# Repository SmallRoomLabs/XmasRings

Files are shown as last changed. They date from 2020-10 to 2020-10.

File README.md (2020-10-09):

# XmasRings

These are cheap 10x10 cm PCBs that are routed/cut into seven rings holding a total of 45 LEDs with individual control using Charlieplexing with a PIC16F1705 microcontroller. There are a couple of different light pattern that it it cycling though.

YouTube video of several XmasRings running (https://www.youtube.com/watch?v=cKff3fn9ruI)

Click image to play video from YouTube

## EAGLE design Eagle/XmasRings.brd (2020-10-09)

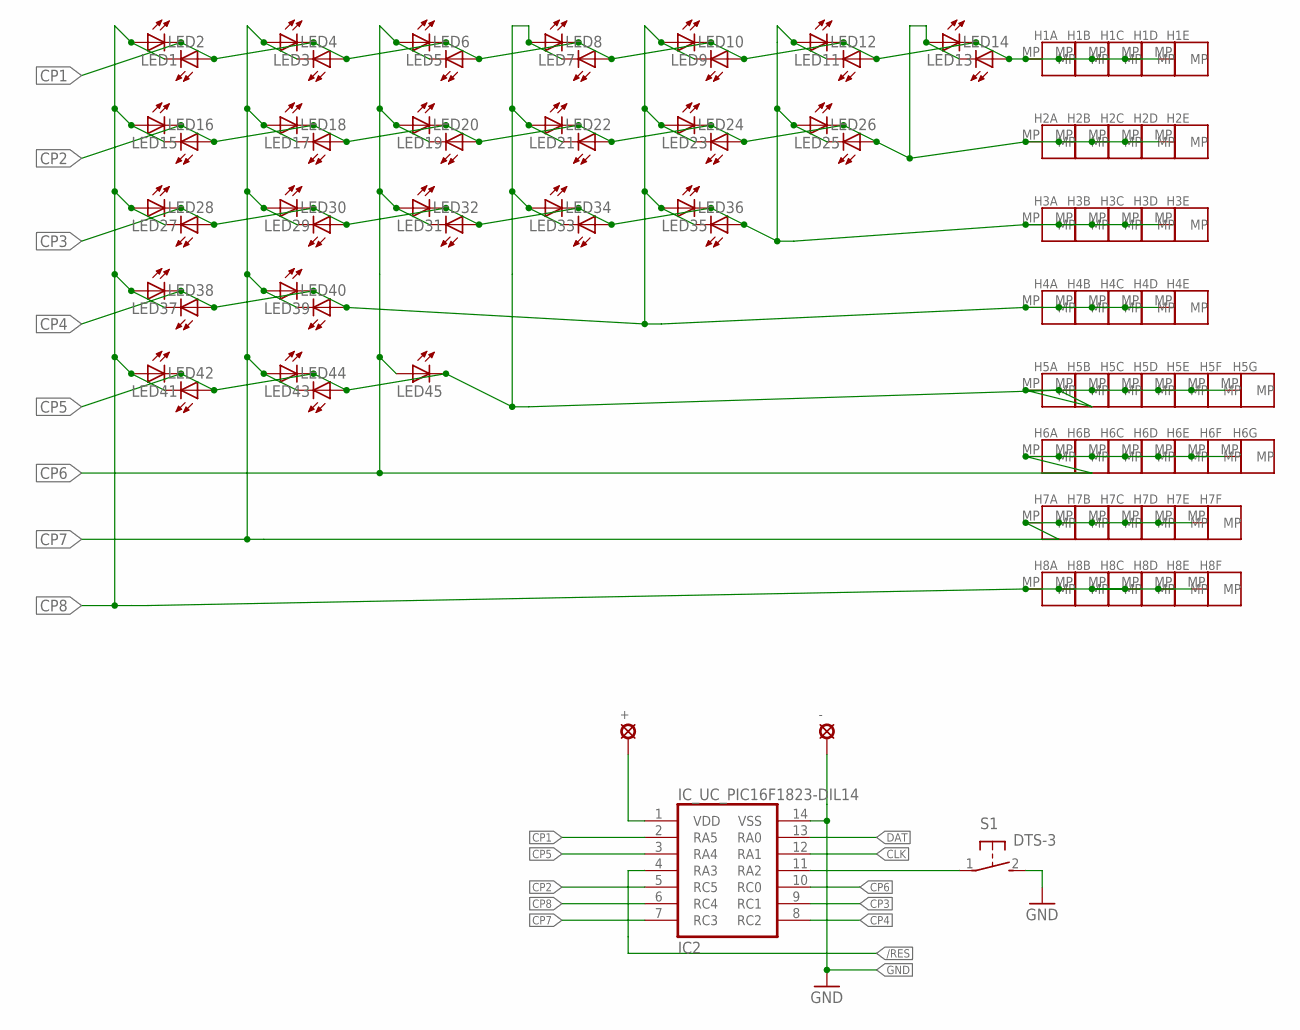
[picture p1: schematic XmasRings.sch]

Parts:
+: LSP10
-: LSP10
H1A, H1B, H1C, H1D, H1E, H2A, H2B, H2C, H2D, H2E, H3A, H3B, H3C, H3D, H3E, H4A, H4B, H4C, H4D, H4E, H5A, H5B, H5C, H5D, H5E, H5F, H5G, H6A, H6B, H6C, H6D, H6E, H6F, H6G, H7A, H7B, H7C, H7D, H7E, H7F, H8A, H8B, H8C, H8D, H8E, H8F: PADH08SS; PAD08SS
IC2: IC_UC_PIC16F1823-DIL14; DIP14
LED1, LED2, LED3, LED4, LED5, LED6, LED7, LED8, LED9, LED10, LED11, LED12, LED13, LED14, LED15, LED16, LED17, LED18, LED19, LED20, LED21, LED22, LED23, LED24, LED25, LED26, LED27, LED28, LED29, LED30, LED31, LED32, LED33, LED34, LED35, LED36, LED37, LED38, LED39, LED40, LED41, LED42, LED43, LED44, LED45: LED5SQ; 5MM-SQ
S1: DTS-3

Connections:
/RES: IC2.4 (RA3)
CLK: IC2.12 (RA1)
CP1: H1A.MP, H1B.MP, H1C.MP, H1D.MP, H1E.MP, IC2.2 (RA5), LED1.C, LED2.A, LED3.C, LED4.A, LED5.C, LED6.A, LED7.C, LED8.A, LED9.C, LED10.A, LED11.C, LED12.A, LED13.C, LED14.A
CP2: H2A.MP, H2B.MP, H2C.MP, H2D.MP, H2E.MP, IC2.5 (RC5), LED13.A, LED14.C, LED15.C, LED16.A, LED17.C, LED18.A, LED19.C, LED20.A, LED21.C, LED22.A, LED23.C, LED24.A, LED25.C, LED26.A
CP3: H3A.MP, H3B.MP, H3C.MP, H3D.MP, H3E.MP, IC2.9 (RC1), LED11.A, LED12.C, LED25.A, LED26.C, LED27.C, LED28.A, LED29.C, LED30.A, LED31.C, LED32.A, LED33.C, LED34.A, LED35.C, LED36.A
CP4: H4A.MP, H4B.MP, H4C.MP, H4D.MP, H4E.MP, IC2.8 (RC2), LED9.A, LED10.C, LED23.A, LED24.C, LED35.A, LED36.C, LED37.C, LED38.A, LED39.C, LED40.A
CP5: H5A.MP, H5B.MP, H5C.MP, H5D.MP, H5E.MP, H5F.MP, H5G.MP, IC2.3 (RA4), LED7.A, LED8.C, LED21.A, LED22.C, LED33.A, LED34.C, LED41.C, LED42.A, LED43.C, LED44.A, LED45.C
CP6: H6A.MP, H6B.MP, H6C.MP, H6D.MP, H6E.MP, H6F.MP, H6G.MP, IC2.10 (RC0), LED5.A, LED6.C, LED19.A, LED20.C, LED31.A, LED32.C, LED45.A
CP7: H7A.MP, H7B.MP, H7C.MP, H7D.MP, H7E.MP, H7F.MP, IC2.7 (RC3), LED3.A, LED4.C, LED17.A, LED18.C, LED29.A, LED30.C, LED39.A, LED40.C, LED43.A, LED44.C
CP8: H8A.MP, H8B.MP, H8C.MP, H8D.MP, H8E.MP, H8F.MP, IC2.6 (RC4), LED1.A, LED2.C, LED15.A, LED16.C, LED27.A, LED28.C, LED37.A, LED38.C, LED41.A, LED42.C
DAT: IC2.13 (RA0)
GND: -.MP, IC2.14 (VSS), S1.2
unnamed: IC2.11 (RA2), S1.1
VCC: +.MP, IC2.1 (VDD)

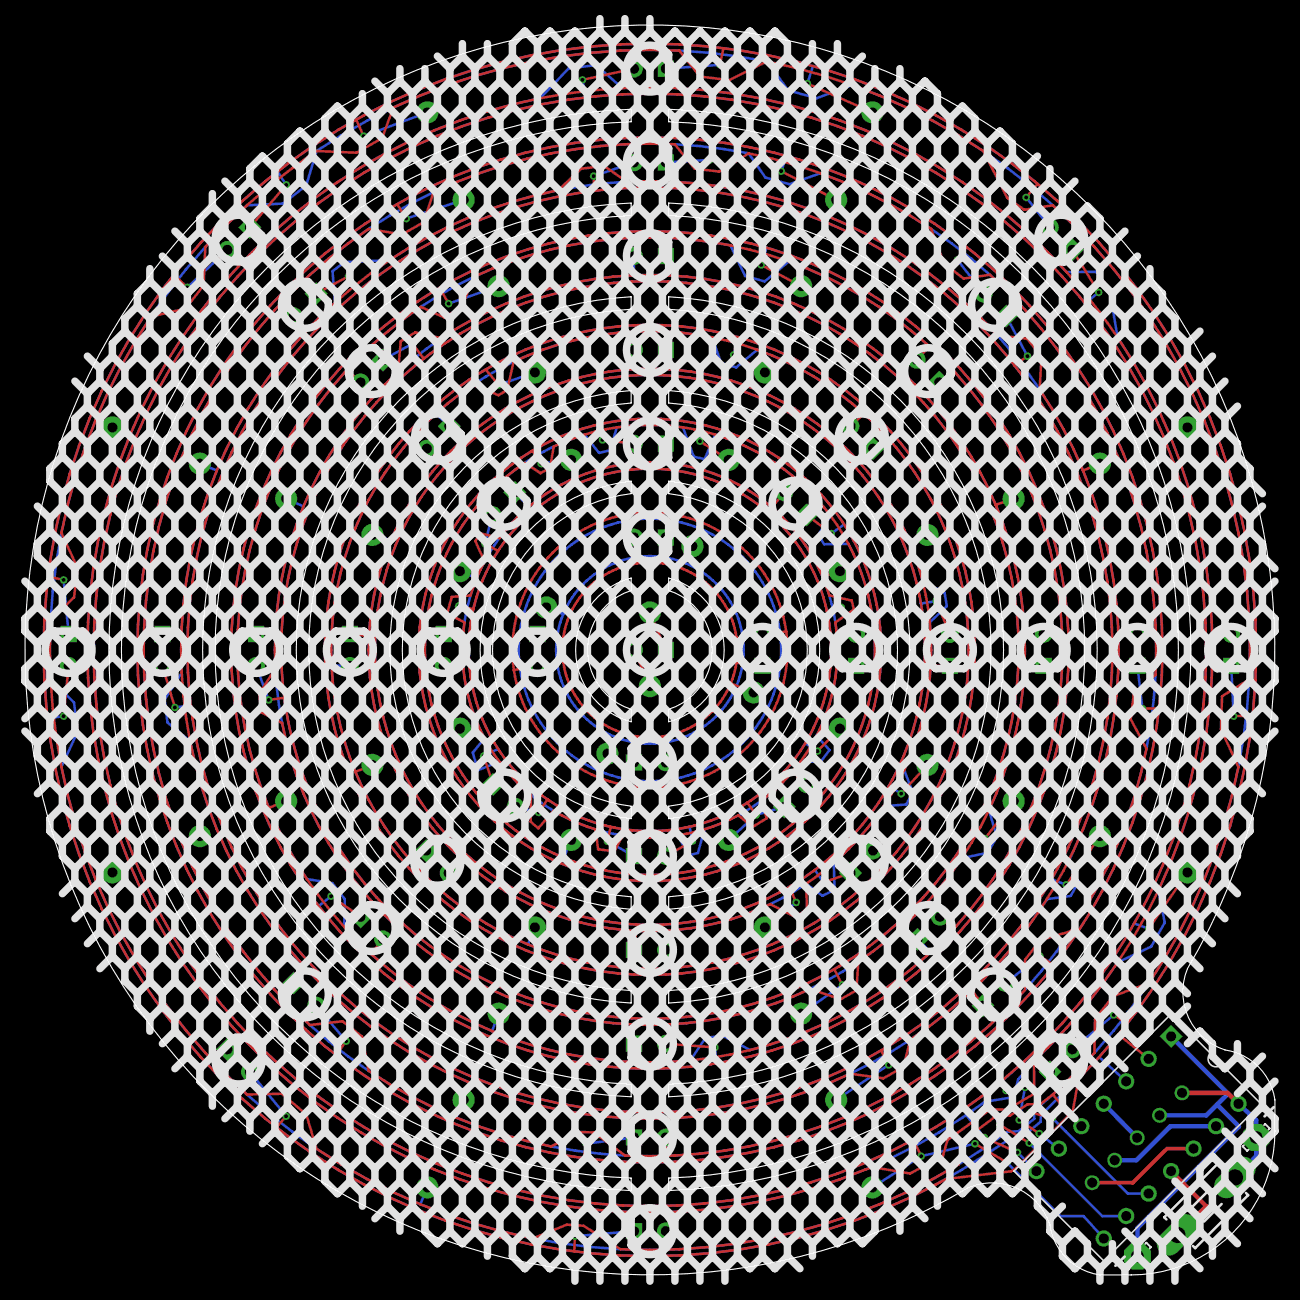
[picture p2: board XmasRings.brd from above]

Board: 2 copper layers, 100.0 x 100.0 mm, 95 parts (0 on the bottom side), 11 nets.

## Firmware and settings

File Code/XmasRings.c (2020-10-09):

//
// PIC16F1705 code for the XmasTree
// Project located at github.com/SmallRoomLabs/XmasRings
// Copright (c) 2016 Mats Engstrom SmallRoomLabs
// Released under the MIT license
//

#define _XTAL_FREQ 32000000

#include <stdint.h>
#include <stdlib.h>
#include <string.h>
#include <xc.h>

#define T0_DIV256 0b0111
#define T0_DIV128 0b0110
#define T0_DIV64  0b0101
#define T0_DIV32  0b0100
#define T0_DIV16  0b0011
#define T0_DIV8   0b0010
#define T0_DIV4   0b0001
#define T0_DIV2   0b0000
#define T0_DIV1   0b1000

// PIC16F1705 Configuration Bit Settings
#pragma config FOSC = INTOSC    // Oscillator Selection Bits (INTOSC oscillator: I/O function on CLKIN pin)
#pragma config WDTE = OFF       // Watchdog Timer Enable (WDT disabled)
#pragma config PWRTE = ON       // Power-up Timer Enable (PWRT enabled)
#pragma config MCLRE = ON       // MCLR Pin Function Select (MCLR/VPP pin function is MCLR)
#pragma config CP = OFF         // Flash Program Memory Code Protection (Program memory code protection is disabled)
#pragma config BOREN = OFF      // Brown-out Reset Enable (Brown-out Reset disabled)
#pragma config CLKOUTEN = OFF   // Clock Out Enable (CLKOUT function is disabled. I/O or oscillator function on the CLKOUT pin)
#pragma config IESO = OFF       // Internal/External Switchover Mode (Internal/External Switchover Mode is disabled)
#pragma config FCMEN = OFF      // Fail-Safe Clock Monitor Enable (Fail-Safe Clock Monitor is disabled)
#pragma config WRT = OFF        // Flash Memory Self-Write Protection (Write protection off)
#pragma config PPS1WAY = ON     // Peripheral Pin Select one-way control (The PPSLOCK bit cannot be cleared once it is set by software)
#pragma config ZCDDIS = ON      // Zero-cross detect disable (Zero-cross detect circuit is disabled at POR)
#pragma config PLLEN = ON       // Phase Lock Loop enable (4x PLL is always enabled)
#pragma config STVREN = ON      // Stack Overflow/Underflow Reset Enable (Stack Overflow or Underflow will cause a Reset)
#pragma config BORV = LO        // Brown-out Reset Voltage Selection (Brown-out Reset Voltage (Vbor), low trip point selected.)
#pragma config LPBOR = OFF      // Low-Power Brown Out Reset (Low-Power BOR is disabled)
#pragma config LVP = ON         // Low-Voltage Programming Enable (Low-voltage programming enabled)

// #pragma config IDLOC0 = 0x01	// Set the User ID data to some
// #pragma config IDLOC1 = 0x23    // values for testing
// #pragma config IDLOC2 = 0x45
// #pragma config IDLOC3 = 0x56

// Defines of bitmasks to make the charlieplex table easier to write
#define b0 (1<<0)   
#define b1 (1<<1)
#define b2 (1<<2)
#define b3 (1<<3)
#define b4 (1<<4)
#define b5 (1<<5)


#define NUMBEROFLEDS  45    // The tree have 45 LEDs in total

//
// This table holds the values for the TRIS and LAT reigsters to
// setup the GPIOs correctly to light up the specified LED
//
const uint8_t charlie[NUMBEROFLEDS*4]={
// TRISA         TRISC         LATA LATC
// ============  ============  ==== ====
   0xFF^(b5|b4), 0xFF^0,       b5,  0,   //  0 1a-5a  RING1
   0xFF^(b5|b4), 0xFF^0,       b4,  0,   //  1 5a-1a
   0xFF^b5,      0xFF^b0,      b5,  0,   //  2 1a-6c
   0xFF^b5,      0xFF^b0,      0,   b0,  //  3 6c-1a
   0xFF^b5,      0xFF^b3,      b5,  0,   //  4 1a-7c
   0xFF^b5,      0xFF^b3,      0,   b3,  //  5 7c-1a
   0xFF^b5,      0xFF^b4,      b5,  0,   //  6 1a-8c
   0xFF^b5,      0xFF^b4,      0,   b4,  //  7 8c-1a

   0xFF^0,       0xFF^(b4|b5), 0,   b5,  //  8 C4 C5  RING2
   0xFF^0,       0xFF^(b4|b5), 0,   b4,  //  9 C5 C4
   0xFF^b5,      0xFF^b5,      b5,  0,   // 10 A5 C5
   0xFF^b5,      0xFF^b5,      0,   b5,  // 11 C5 A5
   0xFF^b5,      0xFF^b1,      b5,  0,   // 12 A5 C1
   0xFF^b5,      0xFF^b1,      0,   b1,  // 13 C1 A5
   0xFF^b5,      0xFF^b2,      b5,  0,   // 14 A5 C4
   0xFF^b5,      0xFF^b2,      0,   b2,  // 15 C4 A5

   0xFF^0,       0xFF^(b2|b5), 0,   b5,  // 16 RC5 RC2  RING3
   0xFF^0,       0xFF^(b2|b5), 0,   b2,  // 17 RC2 RC5
   0xFF^b4,      0xFF^b5,      0,   b5,  // 18 RC5 RA4
   0xFF^b4,      0xFF^b5,      b4,  0,   // 19 RA4 RC5
   0xFF^0,       0xFF^(b0|b5), 0,   b5,  // 20 RC5 RC0
   0xFF^0,       0xFF^(b0|b5), 0,   b0,  // 21 RC0 RC5
   0xFF^0,       0xFF^(b3|b5), 0,   b5,  // 22 RC5 RC3
   0xFF^0,       0xFF^(b3|b5), 0,   b3,  // 23 RC3 RC5

   0xFF^0,       0xFF^(b0|b1), 0,   b1,  // 24 C1 C0  RING4
   0xFF^0,       0xFF^(b0|b1), 0,   b0,  // 25 C0 C1
   0xFF^0,       0xFF^(b1|b3), 0,   b1,  // 26 C1 C3
   0xFF^0,       0xFF^(b1|b3), 0,   b3,  // 27 C3 C1
   0xFF^0,       0xFF^(b1|b4), 0,   b1,  // 28 C1 C4
   0xFF^0,       0xFF^(b1|b4), 0,   b4,  // 29 C4 C1
   0xFF^0,       0xFF^(b1|b5), 0,   b5,  // 30 C5 C1
   0xFF^0,       0xFF^(b1|b5), 0,   b1,  // 31 C1 C5

   0xFF^0,       0xFF^(b2|b3), 0,   b2,  // 32 C2 C3  RING 5
   0xFF^0,       0xFF^(b2|b3), 0,   b3,  // 33 C3 C2
   0xFF^0,       0xFF^(b2|b4), 0,   b2,  // 34 C2 C4
   0xFF^0,       0xFF^(b2|b4), 0,   b4,  // 35 C4 C2
   0xFF^0,       0xFF^(b1|b2), 0,   b1,  // 36 C1 C2
   0xFF^0,       0xFF^(b1|b2), 0,   b2,  // 37 C2 C1
   0xFF^b4,      0xFF^b1,      0,   b1,  // 38 A4 C1
   0xFF^b4,      0xFF^b1,      b4,  0,   // 39 C1 A4

   0xFF^b4,      0xFF^b3,      b4,  0,   // 40 A4 C3  RING 6 (SMALL)
   0xFF^b4,      0xFF^b3,      0,   b3,  // 41 C3 A4
   0xFF^b4,      0xFF^b4,      b4,  0,   // 42 A4 C4
   0xFF^b4,      0xFF^b4,      0,   b4,  // 43 C4 A4

   0xFF^b4,      0xFF^b0,      0,   b0,  // 44 C0 A4  RING 7 (SINGLE)
};

volatile uint8_t tick=0;                // Incremened by IRQ at 0.1s rate
volatile uint8_t ledsOn[NUMBEROFLEDS];
volatile uint8_t maxLitLeds=1;
volatile uint8_t done=0;
uint8_t mode=0;				// Mode 0=Auto change

//
// 0          1          2          3           4          5          6
// 01234567 89012345 67890123 45678901 23456789 01234567 89012345 67890123
//
// 01234567 01234567 01234567 01234567 01234567 01234567 01234567 01234567
//
// LLLLLLLL LLLLLLLL LLLLLLLL LLLLLLLL LLLLLLLL LLLLLmmm mmmmdddd dddddddd
//


//
// Delays the specified time. Return true if button is pressed
//
uint8_t ButtonDelay(uint8_t ms) {
//  while ((ms-- > 0) && (PORTA&(1<<2)) ) {
  while ((ms-- > 0)) {
    __delay_ms(1);
    if (done) return 1;
  }

//  if (PORTA&(1<<2)) {
//    __delay_ms(100);
//    while (!(PORTA&(1<<2))) {};
//    mode++;
//    if (mode>9) mode=0;
//    return 1;
//  }

  return 0;
}


// Macro for turning off all LEDs
#define AllLedOff()  memset(ledsOn,0xFF,NUMBEROFLEDS)

//
// Turn of all LEDs in the specified ring
//
void RingOn(uint8_t ring, uint8_t clear) {
  if (clear) AllLedOff();
  if (ring<5) {
      for (uint8_t i=0; i<8; i++) {
        ledsOn[i]=i+ring*8;
      }
  } else if (ring==5) {
    ledsOn[0]=40;
    ledsOn[1]=41;
    ledsOn[2]=42;
    ledsOn[3]=43;
  } else {
    ledsOn[0]=44;
  }
}

//
// Show animated rings.
//   mode=0 - Go up from largest to smallest
//   mode=1 - Go down from smallest to largest
//   mode-2 - Go up and down
//
void RingUpDown(uint8_t mode) {
  maxLitLeds=8;
  do {
    if (mode==0 || mode==2) {
      for (uint8_t i=0; i<7; i++) {
        RingOn(i,1);  
        if (ButtonDelay(200)) {done=1; break;}
      }
    } 

    if (mode==1) {
      for (uint8_t i=6; i<=6; i--) {
        RingOn(i,1);  
        if (ButtonDelay(200)) {done=1; break;}
      }
    }
    if (mode==2) {
      for (uint8_t i=5; i>0; i--) {
        RingOn(i,1);
        if (ButtonDelay(200)) {done=1; break;}
      }
    }
  } while (!done);
}


//
// Make the top two rings fade in/out while
// flashing a random pixel at the remaining rinds
//
void PulseTopRandomPixel() {
  int8_t dir=1;

  AllLedOff();
  maxLitLeds=1;
  ledsOn[0]=44;
  ledsOn[1]=43;
  ledsOn[2]=42;
  ledsOn[3]=41;
  ledsOn[4]=40;
  do {
    for (uint16_t i=0; i<7; i++) {
      if ((rand()&127)>120) { 
        ledsOn[5]=rand()%40;
      } else {
        ledsOn[5]=0xFF;
      }
    if (ButtonDelay(5)) done=1;
    }
    maxLitLeds+=dir;
    if (maxLitLeds==30) dir=-1;
    if (maxLitLeds==5) dir=1;
  } while (!done);
}



//
// Raindrops falling down from top LED
//

void Rain() {
  uint8_t cnt=0;

  const uint8_t below40[]={32,33,33,34}; 
  const uint8_t below41[]={34,35,35,36};
  const uint8_t below42[]={36,37,37,38};
  const uint8_t below43[]={38,39,39,32};

  maxLitLeds=4;
  AllLedOff();
  do {
    if (cnt++ == 1) {
      cnt=0;
      if (ledsOn[0]==0xFF) {
        ledsOn[0]=44;
      } else if (ledsOn[1]==0xFF) {
        ledsOn[1]=44;
      } else if (ledsOn[2]==0xFF) {
        ledsOn[2]=44;
      } else if (ledsOn[3]==0xFF) {
        ledsOn[3]=44;
      }
    }
    if (ButtonDelay(150)) done=1;
    for (uint8_t i=0; i<maxLitLeds; i++) {
      if (ledsOn[i]==0xFF) continue;
      if (ledsOn[i]==44) {
        ledsOn[i]=40+(rand()&0x03);
      } else if (ledsOn[i]==40) { 
        ledsOn[i]=below40[rand()&0x03];
      } else if (ledsOn[i]==41) { 
        ledsOn[i]=below41[rand()&0x03];
      } else if (ledsOn[i]==42) { 
        ledsOn[i]=below42[rand()&0x03];
      } else if (ledsOn[i]==43) { 
        ledsOn[i]=below43[rand()&0x03];
      } else if (ledsOn[i]>=8) {
        ledsOn[i]-=8;
      } else {
        ledsOn[i]=0xff;
      }
    }
  } while (!done);
}


//
// Random blibs that gets more and more then less
//
void RandomSlowBlips() {
  do {
    for (maxLitLeds=1; maxLitLeds<10; maxLitLeds++) {
      for (uint8_t j=0; j<2; j++) { 
        AllLedOff();
        for (uint8_t i=0; i<maxLitLeds; i++) {
          ledsOn[i]=rand()%NUMBEROFLEDS;
        }    
        if (ButtonDelay(200)) return;
      }
    }
    for (maxLitLeds=9; maxLitLeds>1; maxLitLeds--) {
      for (uint8_t j=0; j<2; j++) { 
        AllLedOff();
        for (uint8_t i=0; i<maxLitLeds; i++) {
          ledsOn[i]=rand()%NUMBEROFLEDS;
        }    
        if (ButtonDelay(200)) return;
      }
    }
  } while (!done);
}


//
// Quck flickering of all leds
//
void Frussel() {
  maxLitLeds=8;
  do {
    for (uint8_t i=0; i<maxLitLeds; i++) {
      ledsOn[i]=rand()%NUMBEROFLEDS;
    }    
    if (ButtonDelay(1)) return;
  } while (!done);
}


//
//
//
void SpiralUpDown() {
  for (uint8_t i=0; i<NUMBEROFLEDS; i++) ledsOn[i]=i;
  do {
    for (maxLitLeds=1; maxLitLeds<NUMBEROFLEDS; maxLitLeds++) {
      if (ButtonDelay(50)) return;
    }      
    for (maxLitLeds=NUMBEROFLEDS; maxLitLeds>1; maxLitLeds--) {
      if (ButtonDelay(50)) return;
    }      
  } while (!done); 
}


//
//
//
void SpiralAway() {
  AllLedOff();
  maxLitLeds=NUMBEROFLEDS;
  do {
    for (uint8_t i=0; i<NUMBEROFLEDS; i++) {
      ledsOn[i]=i;
      if (ButtonDelay(50)) return;
    }
    if (ButtonDelay(50)) return;
    for (uint8_t i=0; i<NUMBEROFLEDS; i++) {
      ledsOn[i]=0xFF;
      if (ButtonDelay(50)) return;
    }
  } while (!done); 
}


//
//
//
void main() {
  OSCCON=0b11110000;		// Use internal oscillator set at 32MHz

  INTCON=0;             // Disable all interrupts
  PIE1=0;               // Disable peripheral interrupts
  PIE2=0;               // Disable more peripheral interrupts
  PIE3=0;               // Disable even more peripheral interrupts
  IOCAN=0x00;           // Disable pin-change interrupts
  IOCAP=0x00;
  IOCCN=0x00;
  IOCCP=0x00;

  ANSELA=0;			        // All GPIOs are digital
  ANSELC=0;
  WPUA=(1<<2);			    // Turn on pullup for the button
  WPUC=0;			          // No pullups at port C
  TRISA=0xFF;			      // All GPIOs are input until the charlieplexing in the IRQ
  TRISC=0xFF;           //   says otherwise

  //
  // Setup Timer0 to generate interrupts at about 4KHz for refreshing
  // the LEDs.  Even if all 45 LEDs are lit/processed the refresh rate
  // will be a flicker-free 87Hz.
  //
  //   fOsc/4      Prescale     8bit counter   45 Leds      
  // 32000000/4 -> 8000000/8 -> 1000000/256 -> 3926/45 -> 87 Hz Refresh 
  //
  OPTION_REG=0x00 | T0_DIV8;    // Wpu enabled, Prescale T0 from Fosc/4 with 8 
  INTCONbits.T0IE=1;            // Enable interrupt on TMR0 overflow
  INTCONbits.GIE=1;             // Global interrupt enable

  AllLedOff();
  for (;;) {
    if (mode==0 || mode==1) {PulseTopRandomPixel(); while (done);}
    if (mode==0 || mode==2) {RingUpDown(0);while (done);}
    if (mode==0 || mode==3) {Rain();while (done);}
    if (mode==0 || mode==4) {SpiralAway();while (done);}
    if (mode==0 || mode==5) {RingUpDown(1);while (done);}
    if (mode==0 || mode==6) {RandomSlowBlips();while (done);}
    if (mode==0 || mode==7) {Frussel();while (done);}
    if (mode==0 || mode==8) {RingUpDown(2);while (done);}
    if (mode==0 || mode==9) {SpiralUpDown();while (done);}
  }
}


//
// Interrupt handler. Takes care of the refreshing of the charlieplexed LEDs by interating
// the list of leds to be lit ledsOn[].  The ledsOn[] array holds the number/id of the LEDs
// to be lit, unused entries in the array are set to 0xFF.
//
void interrupt ISR(void) {
  static uint8_t cnt=0;         // Index into the ledsOn[] array
  static uint16_t localTick=0;  // Internal counter keepint track of the 0.1s tick

  if(INTCONbits.T0IF) {         // If timer flag is set
    INTCONbits.T0IF = 0;        // Clear the interrupt flag 

    if (localTick++>393) {      // Locally count up to 393 before incrementing
      localTick=0;              //     the external 0.1s tick counter
      tick++;

      if (mode==0) {
        if (tick>100 && tick<110) done=1;
        if (tick>=110) {
          done=0;
          tick=0;
        }
      }
    }

    cnt++;
    if (cnt>=maxLitLeds) cnt=0; // Only care about the first "maxLitLeds" in the ledsOn[] array 
    if (ledsOn[cnt]==0xFF) {    // If current entry is no-led then turn of GPIOs
      TRISA=0xFF;
      TRISC=0xFF;
      LATA=0x00;
      LATC=0x00;
    } else {
      uint8_t t=ledsOn[cnt]*4;  // The specified LED should be on. Index into the charlineplexing
      TRISA=charlie[t];         // table and use the values there to setup the GPIOs
      TRISC=charlie[t+1];
      LATA=charlie[t+2];
      LATC=charlie[t+3];
    }
  }

}  

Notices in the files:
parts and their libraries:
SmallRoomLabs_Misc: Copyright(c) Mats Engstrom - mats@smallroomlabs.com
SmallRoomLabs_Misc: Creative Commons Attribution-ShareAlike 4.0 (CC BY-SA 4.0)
